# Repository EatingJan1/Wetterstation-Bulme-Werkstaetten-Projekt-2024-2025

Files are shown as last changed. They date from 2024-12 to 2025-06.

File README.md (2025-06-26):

# Completed school project - archived
the project continues here: https://github.com/EatingJan1/BlueRubberDuck-Weatherstation

## Wetterstation-Bulme-Werkstätten-Projekt-2024/2025

#### Outdoor-Wetterstation
Sensoren:
- BME688: xyz
- UV-Strahlung 
- Luftdruck -> easy BME680(END OF LIVE)/BME688 ist bisl besser und gleiches PINOUT und kostet nur weniger 1€ teurer
- Luftpartikel -> gehackter von Ikea(belüftet Lüfter drin)
- Temperatur -> easy BME680(END OF LIVE)/BME688 ist bisl besser und gleiches PINOUT und kostet nur weniger 1€ teurer
- Regenmenge -> Kippwage & Regenitensität über Zeit
- Windrichtung
- Windgeschwindigkeit
- Bodenfeuchtigkeit 
- UV-Strahlung Winkel -> Berechnen durch von Geolocation
- Dezibel Messung (Optional, Eher nicht)
- Höhenlage -> GPS oder Luftdruck aber zählt eher zu Berchnungen
- CO2 gehalt

##### Belüftete Sensoren  -> Mit 5V Lüfter -> ideal ohne moglichkeit ohne Lüfter
- Temperatur
- Luftfeuchtigkeit
- CO2 Gehalt
- Luftdruck
- Luftpartikel -> gehackter von Ikea (Lüfter drin) -> Teurer es zu hacken / aus zu bauen wie einen Neuen zu Kaufen

##### Berechnung:
- Taupunkt
- kWh/m2 (Sonneneinstrahlung) -> Mehrere Sensoren notwendig zu aufwendig
- gefühlte Temperatur -> Wind + Temp +Sonneneinstrahlung Vielleicht Über temperatur direkt an der gehäusewand ob eher hohe Sonneneinstrahlung oder niedrige 
- Sichtweite -> Feinstaub wichtig 
- Photovoltaik für Outdoor -> Zu viele Variablen
- Windmessung über Ultraschalwandler

##### Funk:
Übertragung: Thread

#### Mini Station:

Misst alle Daten in einem Standard Indoor Raum

Gewollte Messung:
- Temperatur
- Luftfeuchtigkeit
- CO2 Gehalt
- Luftdruck
- Helligkeit (Photowiderstand)

##### Funk:
Übertragung: Thread

#### Daten Station (HUB)
Schittstelle zu unserer Datenbank und ins Local Area Network zur überwachung der Daten

- SD Karten speicherung
- Lan anstatt Wlan
- Lan Driver
- Power über POE
- Überträgt alle Messdaten der letzen seit dem Letzten Timestamp der Datenbank einmalig pro Tag auf unseren MySQL Server. (Welche möglichkeit bzw. Daten auf mehrere Server senden)
    - Server Jan:
        - Im Falle eines Ausfall -> Selbständige Lösung, jedoch Auafall wahrscheinlichkeit höher
        - Gefahr das Daten beschädigt werden / Gelöscht
        - Komplette Administration aller Daten und des Ganzen Systems
        - Individuelle Leistung und weiterleitung (DNS)

    - Schul SQL Datenbank:
        - Keine Informationen über Systemabschaltungen (Wartungs arbeiten, Sommerferien)
        - Keine Informationen von Dauer der Daten speicherung
        - Auf System Administrator angewießen
        - Keine Leistungs bestimmung
        - Kein Eingriff ins Netzwerk
    
    - Externe SQL Server Anbieter:
        - Teuer -> Lohnt sich bei dieser Art von Projekt
        - Hohe Ausfahl Sicherheit
        - Fast keine Gefahr das Daten beschädigt werden
        - Teils auf Support angewießen.
        - Je besser die Hardware desto Teurer pro Monat wobei der Server der selbe bleibt.
        - Netzwerk Limitierungen (Aufpreise)
        - Kann von Datenlacks betroffen sein.

#### Stromversorgung für ALLE STATIONEN:
- USB C 5V -> 3,3V Step-down Converter

## Liste der Sachen für das Projekt:

### ESP's

- Router-CPU: ESP32-S3 -> Externe Antenne -> schlecht, Bessere Reichweiten Kontrolle
- Router-Thread: ESP32-H2 -> Externe Antenne -> schlecht, Bessere Reichweiten Kontrolle
- Devices: ESP32-C6 -> Externe Antenne -> schlecht, Bessere Reichweiten Kontrolle

Externe Antenne:
    https://www.mouser.at/ProductDetail/Johanson-Technology/2450AT14A0100Tqs=YCa%2FAAYMW01CU618jkZ%252BCw%3D%3D&mgh=1&vip=1&utm_id=20600977424&gad_source=1&gbraid=0AAAAA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

### Sensor List:

<table>
 <tr height=20 style='height:15.0pt'>
  <td height=20 class=xl66 width=124 style='height:15.0pt;width:93pt'>Name</td>
  <td class=xl66 width=143 style='width:107pt'>Zweck</td>
  <td class=xl66 width=143 style='width:107pt'>Einheit</td>
  <td class=xl67 width=977 style='width:733pt'>&nbsp;</td>

 <tr height=20 style='height:15.0pt'>
  <td height=20 class=xl65 style='height:15.0pt'>PT 100/1000</td>
  <td class=xl65>Temperaturmessung</td>
  <td class=xl65>°C</td>
  <td></td>
 </tr>
 <tr height=20 style='height:15.0pt'>
  <td height=20 class=xl65 style='height:15.0pt'>Platine</td>
  <td class=xl65>Luftfeuchtigkeit</td>
  <td class=xl65>%</td>
  <td></td>
 </tr>
 <tr height=20 style='height:15.0pt'>
  <td height=20 class=xl65 style='height:15.0pt'>CCS811B-JOPR5K</td>
  <td class=xl65>Luftqualität</td>
  <td class=xl65>ppm</td>
  <td>https://www.digikey.at/de/products/detail/sciosense/CCS811B-JOPR5K/7428298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</td>
 </tr>
 <tr height=20 style='height:15.0pt'>
  <td height=20 class=xl65 style='height:15.0pt'>BMP280</td>
  <td class=xl65>Luftdruck</td>
  <td class=xl65>bar</td>
  <td>https://at.rs-online.com/web/p/drucksensor-ics/8496187</td>
 </tr>
 <tr height=20 style='height:15.0pt'>
  <td height=20 class=xl65 style='height:15.0pt'></td>
  <td class=xl65></td>
  <td class=xl65></td>
  <td></td>
 </tr>
 <tr height=0 style='display:none'>
  <td width=124 style='width:93pt'></td>
  <td width=143 style='width:107pt'></td>
  <td width=143 style='width:107pt'></td>
  <td width=977 style='width:733pt'></td>
 </tr>
</table>

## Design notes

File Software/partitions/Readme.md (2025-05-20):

# Custom Partition Tables on ESP32 (PlatformIO)

Why Use Custom Partitions?

The default partition table on the ESP32 is suitable for simple projects, but many applications need a different memory layout. Here are some reasons why you might want to use a custom partition table:

* Larger SPIFFS or LittleFS Storage: Need more space for files? Increase the size of your file system partition.
* Multiple App Partitions: For over-the-air (OTA) updates or fallback firmware.
* NVS Tweaks: Allocate more room for non-volatile storage (NVS).
* Custom Data Sections: Store configuration data, logs, or calibration values in dedicated partitions.
* PSRAM Optimization: Match partitioning to specific PSRAM setups.
Custom partitioning helps you get the most out of your flash memory depending on your application’s needs.

Update platformio.ini to Use the Custom Partition
Add or modify the board_build.partitions option:

## Update `platformio.ini` to Use the Custom Partition Table

To tell PlatformIO to use your custom partition layout, open your `platformio.ini` file and add or modify the following line:

```ini
board_build.partitions = partitions/partitions.csv
[env:esp32dev]
platform = espressif32
board = esp32dev
framework = arduino

;Use a custom partition layout
board_build.partitions = partitions/partitions.csv
```

📁 Make sure your partitions.csv file is located in the partitions/ subfolder of your project directory.
PlatformIO will automatically include this partition scheme when compiling and flashing your project.

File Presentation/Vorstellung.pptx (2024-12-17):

## Wetterstation

## Must2Have

Indoor:
- Temperatur
- Luftfeuchtigkeit
- Luftdruck
- CO2

Outdoor:
- Temperatur
- Luftfeuchtigkeit
- Luftdruck
- Regenmenge
- Windrichtung
- Windgeschwindigkeit

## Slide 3

Blockschaltbild
Minimaler Ausbau

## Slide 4

Nice2Have

Indoor:
LED‘s→ Visualisierung von Optimal werten
Luftpartikel

Outdoor:
Luftpartikelsensor
Sonnenlichtabhängige Sensoren
Windmessung über Ultraschall
Gefühlte Temperatur

## Nice2Have Berechnungen

Outdoor:
Sichtweite
Einstrahlungsenergie pro m²
kWh/m² (Sonneneinstrahlung)
Taupunkt

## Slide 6

Nice2Have

Für alle Geräte:
OTA → ermöglicht Updates von Anwendungen, Diensten und Konfigurationen über ein Funknetz – ohne physischen Kontakt, also over the air
HUB:
Power over Ethernet (POE) → Ermöglicht es Daten und elektrische Energie über einen RJ-45 Kabel zu transportieren
Datenspeicherung über längere Zeit

Second Outdoor Sensor:
Bodenfeuchtigkeit

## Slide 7

Nice2Have
Funkprotokoll:
Thread

Vorteile gegenüber WLAN:
Geringer Stromverbrauch
Unterstützt Mesh-Netzwerke → Geräte können direkt miteinander kommunizieren und Signale weiterleiten
Ist besser für Smart-Home Geräte ausgelegt
Thread-Netzwerke können Tausende von Geräten effizient verbinden
arbeitet in einem Frequenzbereich der weniger überlastet ist
Beinhaltet integrierte Sicherheitsfunktionen
Es gibt keinen zentralen Router

## Blockschaltbild Maximaler Ausbau

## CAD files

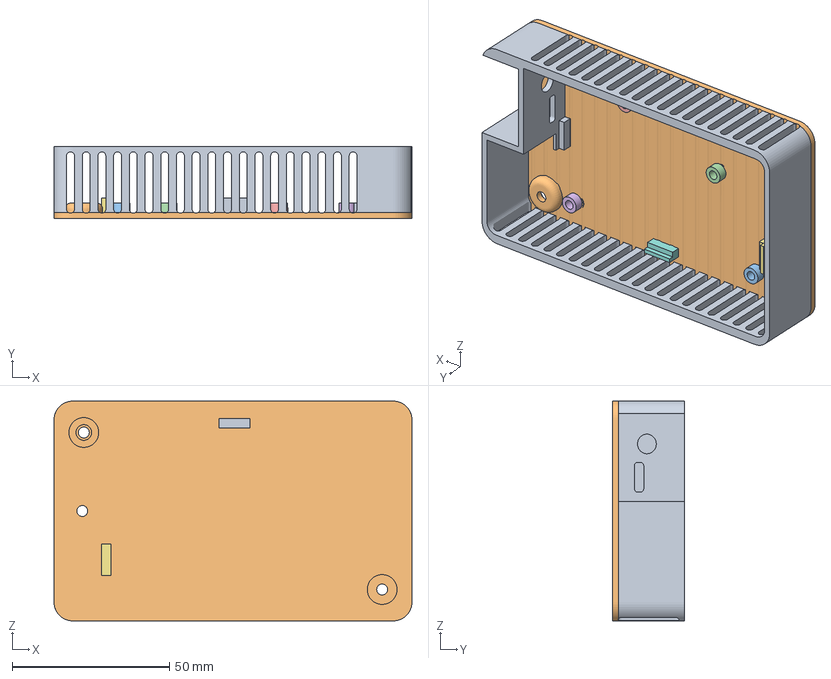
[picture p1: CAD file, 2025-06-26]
3D Model/Indoor/Indoor-bottom v34.3mf
114.0 x 23.0 x 70.0 mm
Außenwand
Grundplatte
HalterungP1
HalterungP2
HalterungP3
HalterungP4
PStütze1 (1)
PStütze1
PStütze3

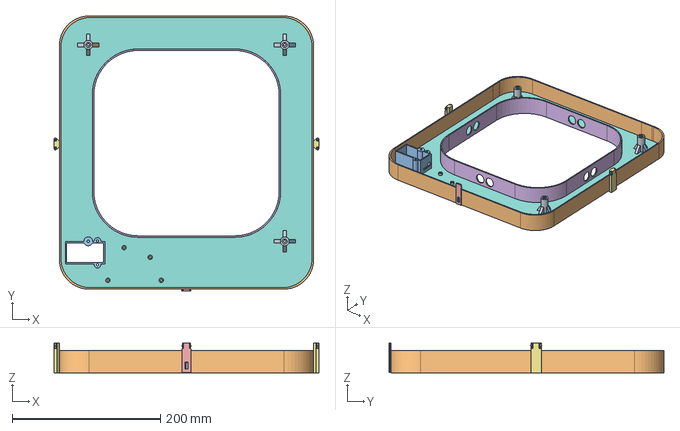
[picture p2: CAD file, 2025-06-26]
3D Model/Outdoor/Outdoor-bottom v38.step
357.0 x 371.0 x 40.0 mm

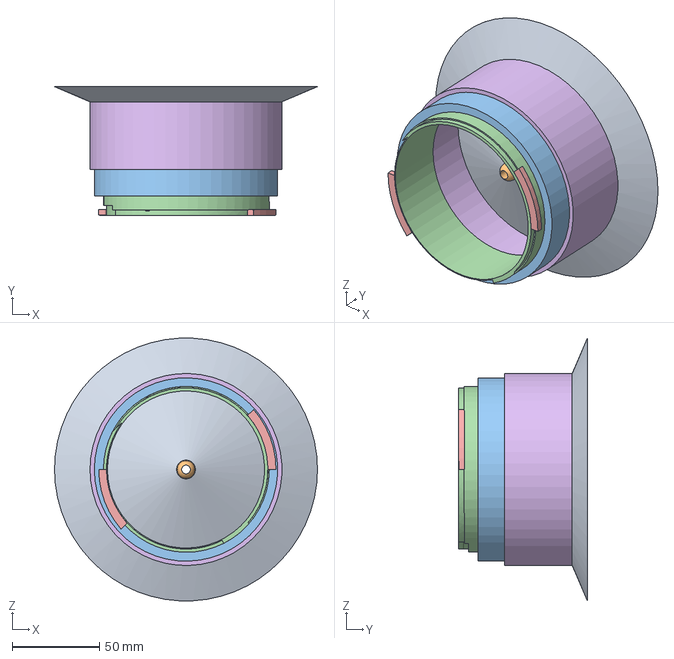
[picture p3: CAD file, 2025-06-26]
3D Model/Outdoor/Hyetometer-top v23.step
150.7 x 73.7 x 150.5 mm

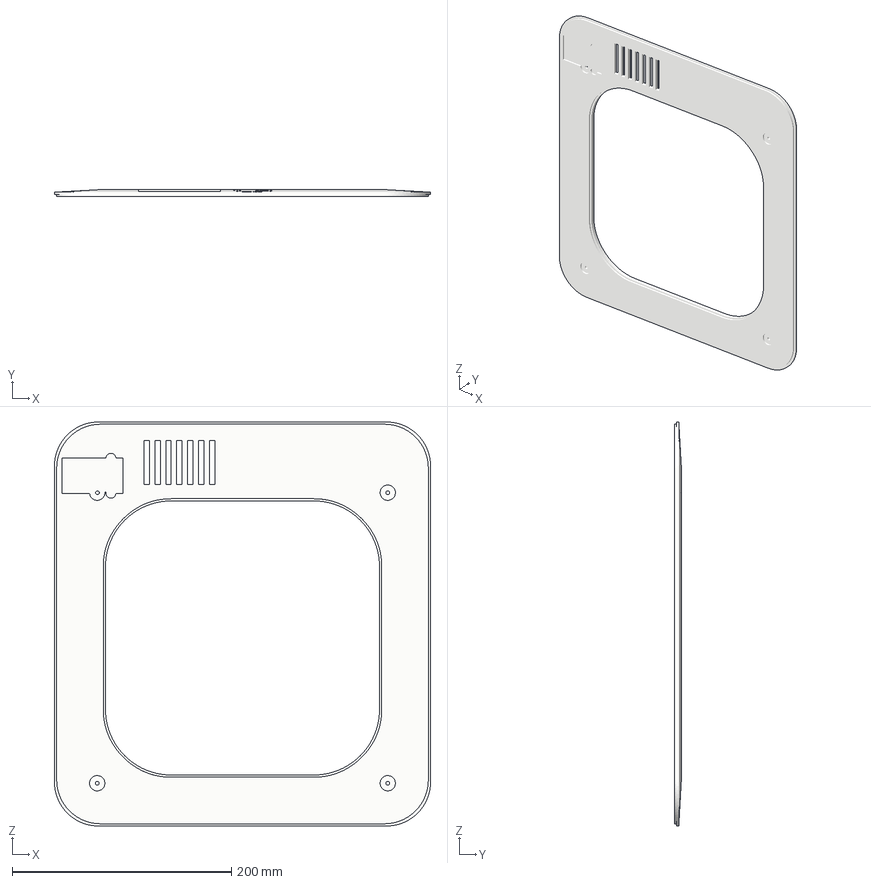
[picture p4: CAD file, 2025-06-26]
3D Model/Outdoor/Outdoor-top v38.3mf
343.0 x 6.50 x 368.5 mm
Körper37
Körper39
Körper40

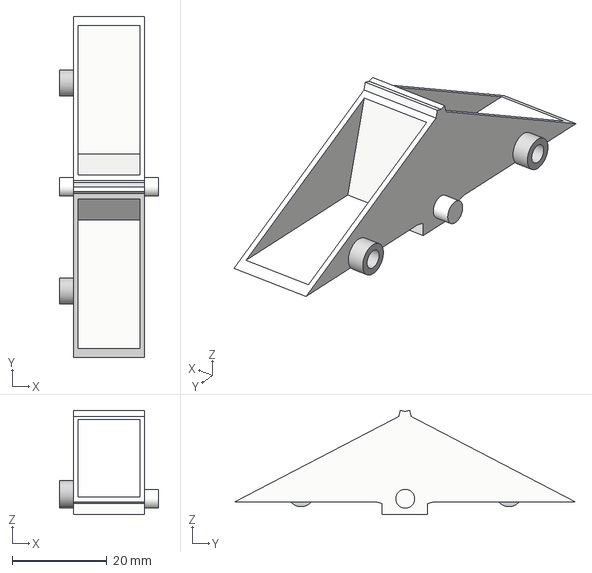
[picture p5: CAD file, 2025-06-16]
3D Model/Outdoor/threshold-Hyetometer v4.step
21.0 x 72.0 x 22.0 mm

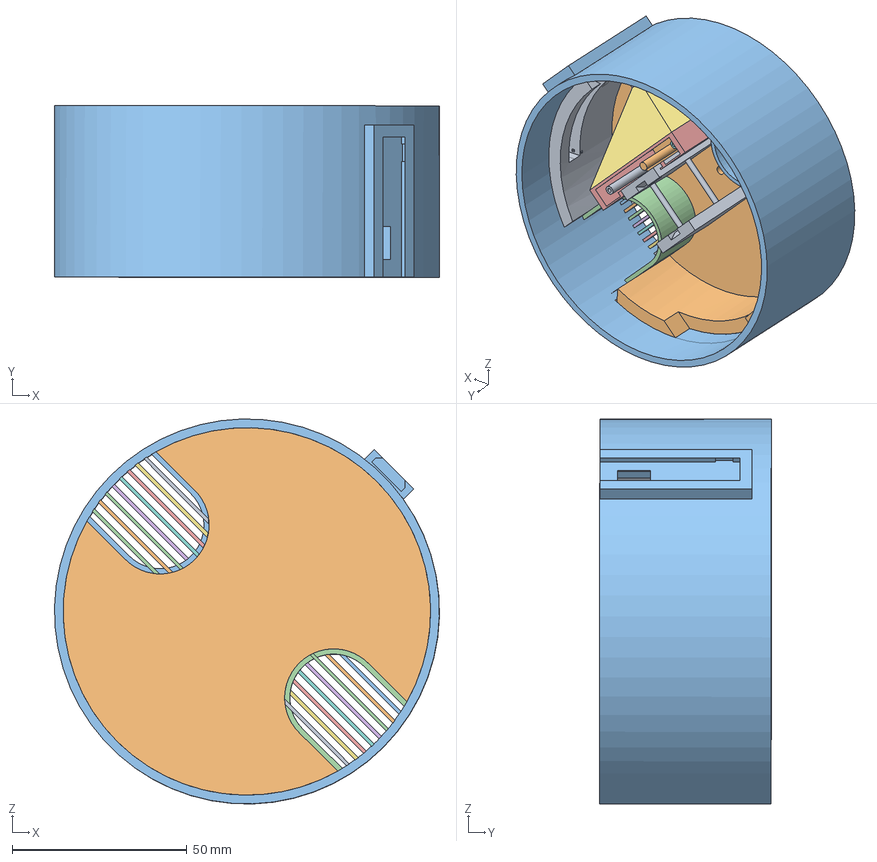
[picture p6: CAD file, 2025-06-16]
3D Model/Outdoor/Trichter-bottom v22.step
110.0 x 49.2 x 110.0 mm

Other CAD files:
3D Model/Outdoor/Hyetometer-bottom v22.3mf
3D Model/Indoor/Indoor-bottom v34.stl
3D Model/Outdoor/Hyetometer-bottom v22.stl
3D Model/Outdoor/Hyetometer-top v23.3mf
3D Model/Outdoor/Hyetometer-top v23.stl
3D Model/Outdoor/Outdoor-bottom v38.3mf
3D Model/Outdoor/Outdoor-bottom v38.stl
3D Model/Outdoor/threshold-Hyetometer v4.3mf
3D Model/Outdoor/threshold-Hyetometer v4.stl

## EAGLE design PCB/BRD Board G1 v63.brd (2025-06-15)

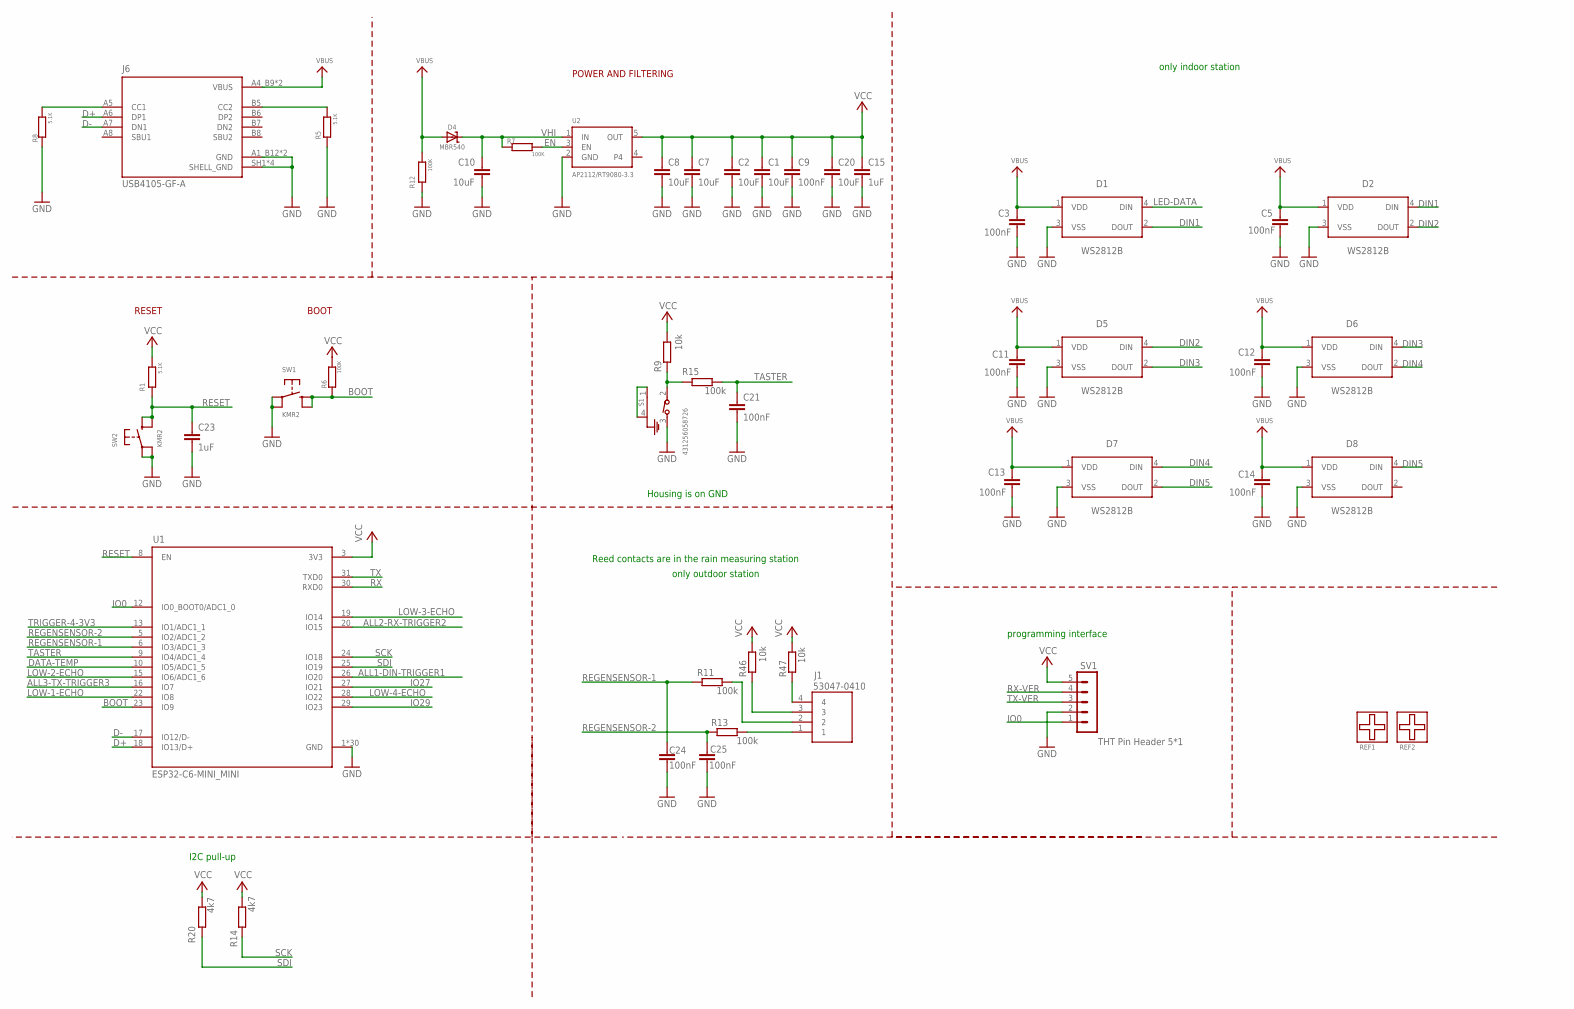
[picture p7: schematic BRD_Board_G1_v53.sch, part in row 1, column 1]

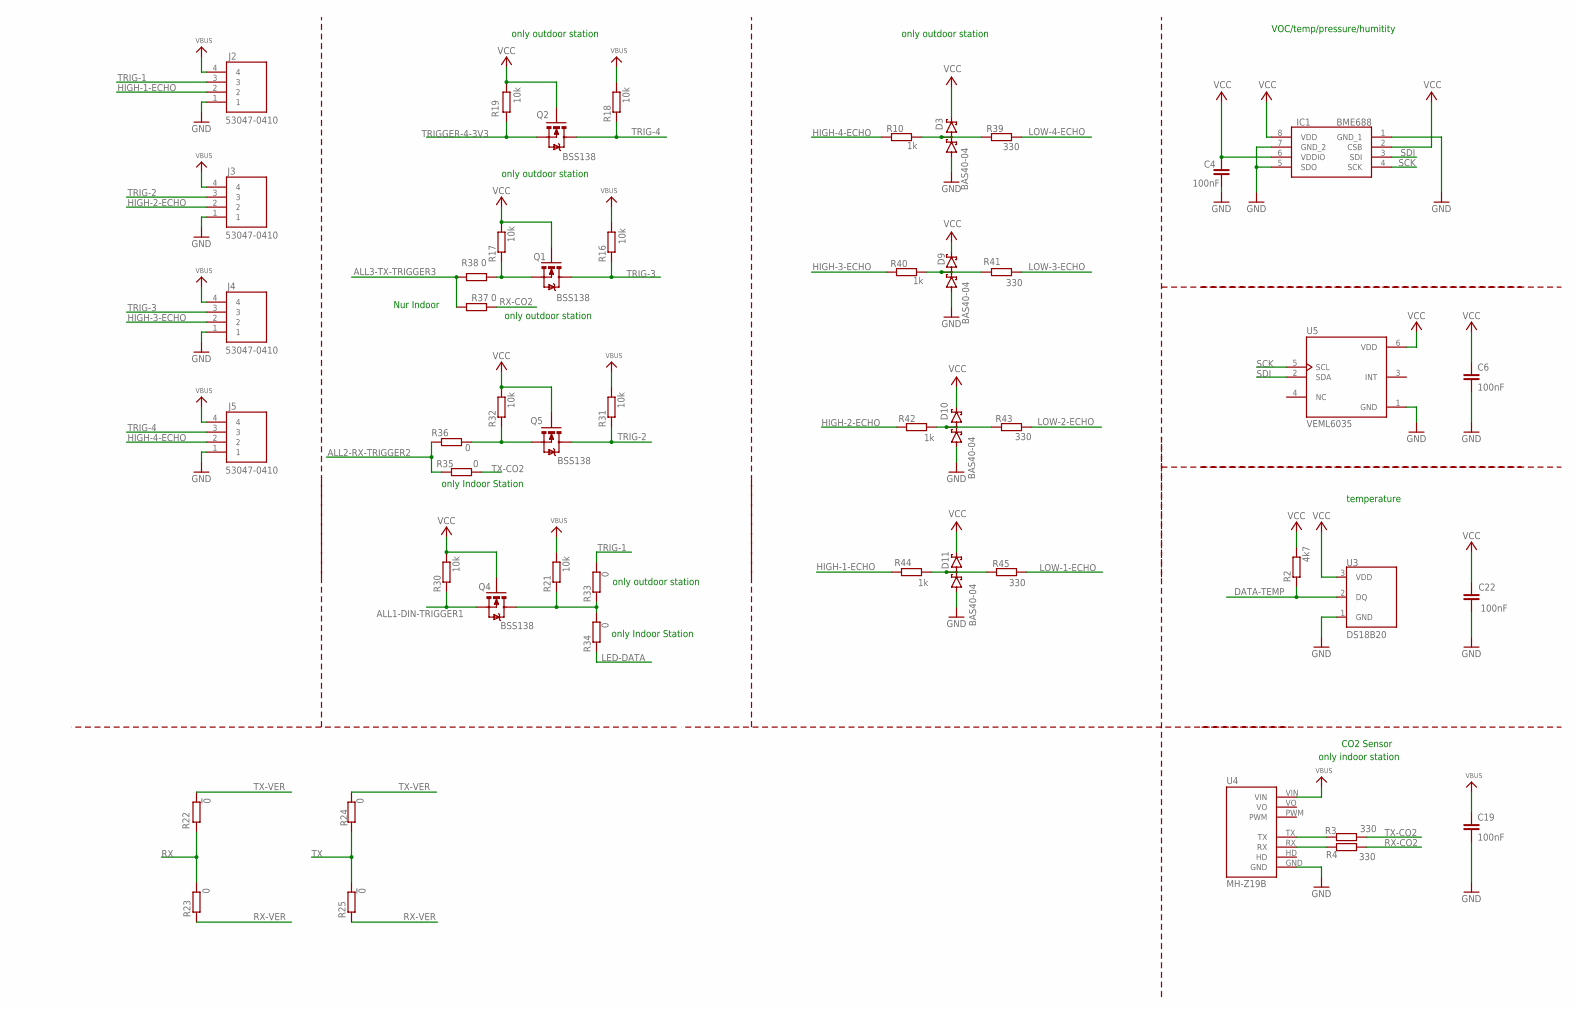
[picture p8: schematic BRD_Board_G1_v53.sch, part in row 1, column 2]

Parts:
C1, C2, C7, C8, C10, C20: 10uF; C0805K
C3, C4, C5, C6, C9, C11, C12, C13, C14, C19, C21, C22, C24, C25: 100nF; C0603K
C15: 1uF; C0603K
C23: 1uF; C0805K
D1, D2, D5, D6, D7, D8: WS2812B
D3, D9, D10, D11: BAS40-04; SOT23
D4: MBR540; SOD-123
IC1: BME688
J1, J2, J3, J4, J5: 53047-0410; 530470410
J6: USB4105-GF-A; GCT_USB4105-GF-A
Q1, Q2, Q4, Q5: BSS138; SOT23
R1, R5, R8: 5.1K; R0805
R2, R14, R20: 4k7; R0805
R3, R4, R39, R41, R43, R45: 330; R0805
R6, R7, R12: 100K; R0805
R9, R16, R17, R18, R19, R21, R30, R31, R32, R46, R47: 10k; R0805
R10, R40, R42, R44: 1k; R0805
R11, R13, R15: 100k; R0805
R22, R25: !0; R0805
R23, R24, R33, R34, R35, R36, R37, R38: 0; R0805
REF1, REF2: FIDUCIALFIDU_1_3_MM; FIDU_1_3MM
S1: 431256058726; 4312560587X6
SV1: THT Pin Header 5*1; MAR05-1
SW1, SW2: KMR2; BTN_RKB2_4.6X2.8
U1: ESP32-C6-MINI_MINI; ESP32-PICO-MINI
U2: AP2112/RT9080-3.3; SOT23-5; JLC_ROTATION 0
U3: DS18B20; TO-92-AMMO
U4: MH-Z19B
U5: VEML6035; XDCR_VEML6035

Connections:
ALL1-DIN-TRIGGER1: Q4.2 (S), R30.1, U1.26 (IO20)
ALL2-RX-TRIGGER2: R35.1, R36.1, U1.20 (IO15)
ALL3-TX-TRIGGER3: R37.1, R38.1, U1.16 (IO7)
BOOT: R6.1, SW1.B (S), SW1.B' (S1), U1.23 (IO9)
D+: J6.A6 (DP1), U1.18 (IO13/D+)
D-: J6.A7 (DN1), U1.17 (IO12/D-)
DATA-TEMP: R2.1, U1.10 (IO5/ADC1_5), U3.2 (DQ)
DIN1: D1.2 (DOUT), D2.4 (DIN)
DIN2: D2.2 (DOUT), D5.4 (DIN)
DIN3: D5.2 (DOUT), D6.4 (DIN)
DIN4: D6.2 (DOUT), D7.4 (DIN)
DIN5: D7.2 (DOUT), D8.4 (DIN)
EN: R7.1, U2.3 (EN)
GND: C1.2, C2.2, C3.2, C4.1, C5.2, C6.2, C7.2, C8.2, C9.2, C10.2, C11.2, C12.2, C13.2, C14.2, C15.2, C19.2, C20.2, C21.2, C22.1, C23.2, C24.2, C25.2, D1.3 (VSS), D2.3 (VSS), D3.1 (A1), D5.3 (VSS), D6.3 (VSS), D7.3 (VSS), D8.3 (VSS), D9.1 (A1), D10.1 (A1), D11.1 (A1), IC1.1 (GND_1), IC1.5 (SDO), IC1.7 (GND_2), J2.1, J3.1, J4.1, J5.1, J6.A1_B12 (GND), J6.B1_A12 (GND), J6.SH1 (SHELL_GND), J6.SH2 (SHELL_GND), J6.SH3 (SHELL_GND), J6.SH4 (SHELL_GND), R5.1, R8.1, R12.1, S1.3, SV1.2, SW1.A, SW1.A' (P1), SW2.A, SW2.A' (P1), U1.1 (GND), U1.2 (GND), U1.11 (GND), U1.14 (GND), U1.36 (GND), U1.37 (GND), U1.38 (GND), U1.39 (GND), U1.40 (GND), U1.41 (GND), U1.42 (GND), U1.43 (GND), U1.44 (GND), U1.45 (GND), U1.46 (GND), U1.47 (GND), U1.48 (GND), U1.49 (GND), U1.50 (GND), U1.51 (GND), U1.52 (GND), U1.53 (GND), U1.54 (GND), U1.55 (GND), U1.56 (GND), U1.57 (GND), U1.58 (GND), U1.59 (GND), U1.60 (GND), U1.61 (GND), U2.2 (GND), U3.1 (GND), U4.GND, U5.1 (GND)
HIGH-1-ECHO: J2.2, R44.2
HIGH-2-ECHO: J3.2, R42.2
HIGH-3-ECHO: J4.2, R40.2
HIGH-4-ECHO: J5.2, R10.2
IO0: SV1.1, U1.12 (IO0_BOOT0/ADC1_0)
IO27: U1.27 (IO21)
IO29: U1.29 (IO23)
LED-DATA: D1.4 (DIN), R34.1
LOW-1-ECHO: R45.1, U1.22 (IO8)
LOW-2-ECHO: R43.1, U1.15 (IO6/ADC1_6)
LOW-3-ECHO: R41.1, U1.19 (IO14)
LOW-4-ECHO: R39.1, U1.28 (IO22)
unnamed: R4.2, U4.RX
unnamed: R9.1, R15.2, S1.2
unnamed: R3.2, U4.TX
unnamed: S1.1 (GND1), S1.4 (GND)
unnamed: D3.3 (C1A2), R10.1, R39.2
unnamed: D9.3 (C1A2), R40.1, R41.2
unnamed: Q1.2 (S), R17.1, R38.2
unnamed: J6.A5 (CC1), R8.2
unnamed: J6.B5 (CC2), R5.2
unnamed: D10.3 (C1A2), R42.1, R43.2
unnamed: D11.3 (C1A2), R44.1, R45.2
unnamed: J1.3, R46.1
unnamed: J1.4, R47.1
unnamed: Q5.2 (S), R32.1, R36.2
unnamed: Q4.3 (D), R21.1, R33.1, R34.2
unnamed: J1.2, R11.1
unnamed: J1.1, R13.1
REGENSENSOR-1: C24.1, R11.2, U1.6 (IO3/ADC1_3)
REGENSENSOR-2: C25.1, R13.2, U1.5 (IO2/ADC1_2)
RESET: C23.1, R1.1, SW2.B (S), SW2.B' (S1), U1.8 (EN)
RX: R22.2, R23.1, U1.30 (RXD0)
RX-CO2: R4.1, R37.2
RX-VER: R23.2, R25.2, SV1.4
SCK: IC1.4 (SCK), R14.1, U1.24 (IO18), U5.5 (SCL)
SDI: IC1.3 (SDI), R20.1, U1.25 (IO19), U5.2 (SDA)
TASTER: C21.1, R15.1, U1.9 (IO4/ADC1_4)
TRIG-1: J2.3, R33.2
TRIG-2: J3.3, Q5.3 (D), R31.1
TRIG-3: J4.3, Q1.3 (D), R16.1
TRIG-4: J5.3, Q2.3 (D), R18.1
TRIGGER-4-3V3: Q2.2 (S), R19.1, U1.13 (IO1/ADC1_1)
TX: R24.2, R25.1, U1.31 (TXD0)
TX-CO2: R3.1, R35.2
TX-VER: R22.1, R24.1, SV1.3
VBUS: C3.1, C5.1, C11.1, C12.1, C13.1, C14.1, C19.1, D1.1 (VDD), D2.1 (VDD), D4.A, D5.1 (VDD), D6.1 (VDD), D7.1 (VDD), D8.1 (VDD), J2.4, J3.4, J4.4, J5.4, J6.A4_B9 (VBUS), J6.B4_A9 (VBUS), R12.2, R16.2, R18.2, R21.2, R31.2, U4.VIN
VCC: C1.1, C2.1, C4.2, C6.1, C7.1, C8.1, C9.1, C15.1, C20.1, C22.2, D3.2 (C2), D9.2 (C2), D10.2 (C2), D11.2 (C2), IC1.2 (CSB), IC1.6 (VDDIO), IC1.8 (VDD), Q1.1 (G), Q2.1 (G), Q4.1 (G), Q5.1 (G), R1.2, R2.2, R6.2, R9.2, R14.2, R17.2, R19.2, R20.2, R30.2, R32.2, R46.2, R47.2, SV1.5, U1.3 (3V3), U2.5 (OUT), U3.3 (VDD), U5.6 (VDD)
VHI: C10.1, D4.C, R7.2, U2.1 (IN)

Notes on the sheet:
POWER AND FILTERING
RESET
CO2 Sensor
temperature
VOC/temp/pressure/humitity
Reed contacts are in the rain measuring station
programming interface
Housing is on GND
only indoor station
only outdoor station
Nur Indoor
only Indoor Station
BOOT
I2C pull-up

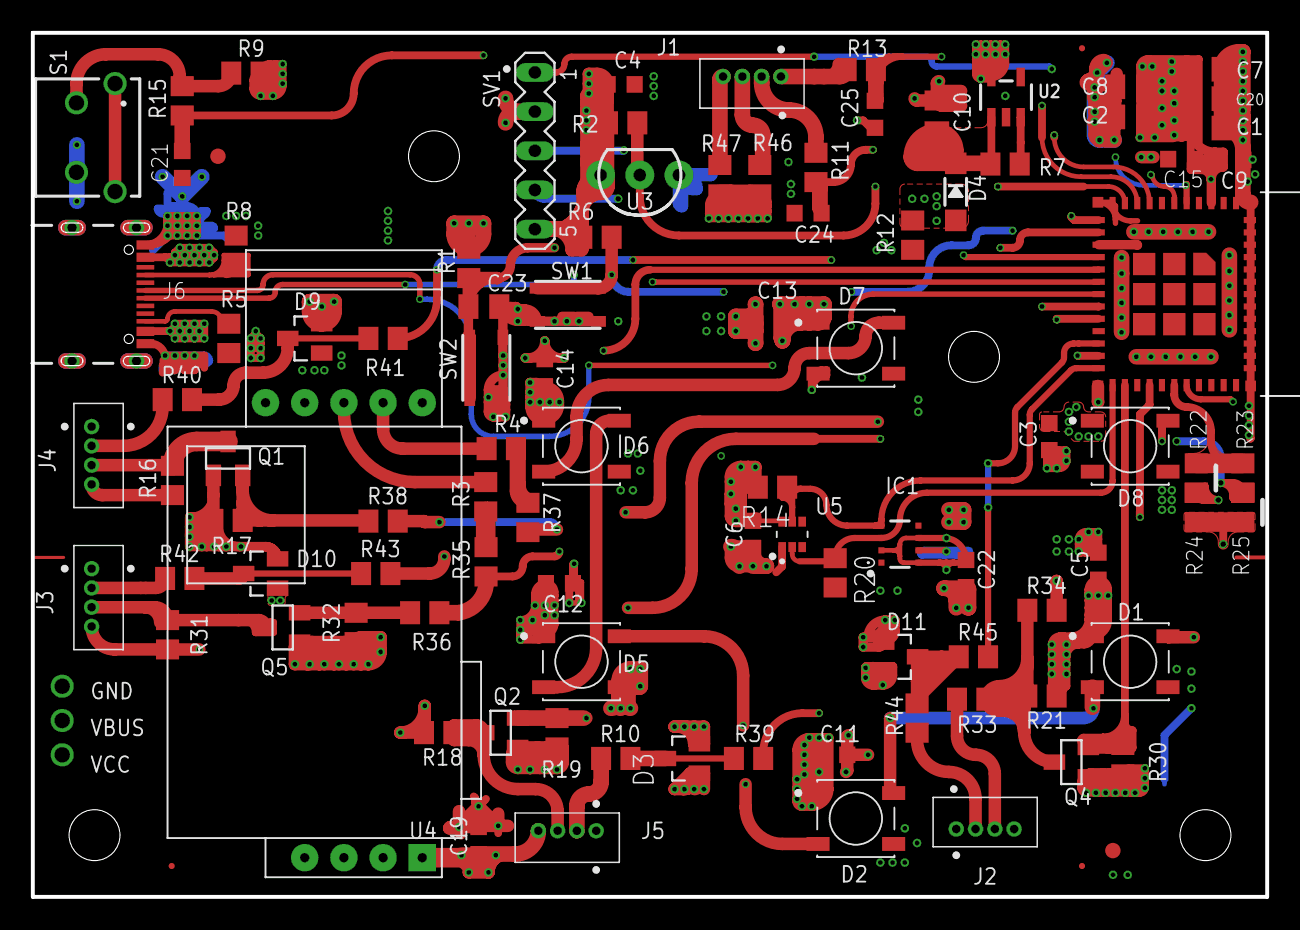
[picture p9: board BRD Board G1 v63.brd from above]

Board: 4 copper layers, 80.0 x 56.0 mm, 98 parts (0 on the bottom side), 61 nets.

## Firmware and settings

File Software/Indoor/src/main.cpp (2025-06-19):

#include <Matter.h>
#include <WiFi.h>
#include "LIB/Matter/matter_endpoints/MatterAirQualitySensor.h"
#include "LIB/Matter/matter_endpoints/MatterLightSensor.h"
#include "LIB/LEDAnimation/LEDAnimation.h"
#include <MHZ19.h>
#include <SoftwareSerial.h>
#include <bme68xLibrary.h>
#include <SparkFun_VEML6030_Ambient_Light_Sensor.h>
#include <Wire.h>

#include "pinout_brd_V1:0.h"

MatterTemperatureSensor Temp;
MatterHumiditySensor Hum;
MatterPressureSensor Pres;
MatterAirQualitySensor CO2;
MatterLightSensor Light;
MatterOnOffPlugin OnOffPlugin;

MHZ19 mhz19;
SoftwareSerial CO2Serial(RX_CO2, TX_CO2);


Bme68x bme;
SparkFun_Ambient_Light light_I2C(AL_ADDR);

Adafruit_NeoPixel strip(NUM_PIXELS, WS2812_Pin, NEO_GRB + NEO_KHZ800);
LEDAnimation Led = LEDAnimation(strip, NUM_PIXELS); 


const char *ssid = "";
const char *password = "";



uint32_t button_time_stamp = 0;                
bool button_state = false;                     
uint32_t time_diff = 0;
const uint32_t decommissioningTimeout = 20000;
const uint32_t co2timer = 5000;

float gain = .125;
int integrationTime = 800;
int powMode = 2; // range [1; 4] 


void setaqilight(uint8_t aqi)
{
    if (1 == aqi)
    {
      Led.setColor(strip.Color(0, 0, 255));
      Led.setAnimation(AnimationType::Static);
    }
    else if (2 == aqi)
    {
      Led.setColor(strip.Color(0, 255, 0));
      Led.setAnimation(AnimationType::Static);
    }
    else if (3 == aqi)
    {
      Led.setColor(strip.Color(213, 78, 0));
      Led.setAnimation(AnimationType::Static);
    }
    else if (4 == aqi)
    {
      Led.setColor(strip.Color(255, 0, 0));
      Led.setAnimation(AnimationType::Static);
    }
    else if (5 == aqi)
    {
      Led.setAnimation(AnimationType::CriticalWarning);
    }
    else
    {
        //Led.setAnimation(AnimationType::None);
    }
}

bool setPluginOnOff(bool state) {
  Serial.printf("User Callback :: New Plugin State = %s\r\n", state ? "ON" : "OFF");
  if (state) {
    setaqilight(CO2.getAirQuality());
  } else {
    Led.setAnimation(AnimationType::None);
  }

  //matterPref.putBool(onOffPrefKey, state);
  return true;
}

void setup() {
  Serial.begin(115200);
  
  Led.setColor(strip.Color(0,0,255));
  Led.setAnimation(AnimationType::StartUp);
  
  delay(1000);

  pinMode(Button_Pin, INPUT);

  WiFi.begin(ssid, password);

  
  // Wait for WiFi connection
  uint32_t counter = 0;
  while (WiFi.status() != WL_CONNECTED) {

    Led.setColor(strip.Color(90, 70, 0));
    Led.setAnimation(AnimationType::Connection);
    // WiFi searching feedback
    Serial.print(".");
    delay(500);
    // adds a new line every 30 seconds
    counter++;
    if (!(counter % 60)) {
      Serial.println();
    }
  }

  Serial.println();



  Led.setAnimation(AnimationType::None);

  Temp.begin();
  Hum.begin();
  Pres.begin();
  Light.begin();
  CO2.begin();
  OnOffPlugin.begin(true);
  OnOffPlugin.onChange(setPluginOnOff);

  Matter.begin();


  if (!Matter.isDeviceCommissioned()) {
    Serial.println("");
    Serial.println("Indoor weather Station is not commissioned yet.");
    Serial.println("Initiate the device discovery in your Matter environment.");
    Serial.println("Commission it to your Matter hub with the Matter Label");
    Serial.printf("Manual pairing code: %s\r\n", Matter.getManualPairingCode().c_str());
    Serial.printf("QR code URL: %s\r\n", Matter.getOnboardingQRCodeUrl().c_str());
    
    Led.setColor(strip.Color(0,0,255));   
    Led.setAnimation(AnimationType::Rotating);

    uint32_t timeCount = 0;


    while (!Matter.isDeviceCommissioned()) {
      delay(100);
      if ((timeCount++ % 100) == 0) {
        Serial.println("Indoor weather Station not commissioned yet. Waiting for commissioning.");
      }
    }
    
    Serial.println("Indoor weather Station is commissioned and connected to Wi-Fi. Ready for use.");
    Led.setAnimation(AnimationType::None);
  }
  if(Matter.isDeviceCommissioned())
  {
    OnOffPlugin.updateAccessory();  // configure the Plugin based on initial state
  }

  CO2Serial.begin(9600);
  mhz19.begin(CO2Serial);

  mhz19.autoCalibration(true);

  Wire.begin(SDI, SCK, 100000);

  bme.begin(BME_ADDR, Wire);
  
  if(bme.checkStatus())
	{
    if (bme.checkStatus() == BME68X_ERROR)
		{
      Serial.println("Sensor error:" + bme.statusString());
		}
		else if (bme.checkStatus() == BME68X_WARNING)
		{
      Serial.println("Sensor Warning:" + bme.statusString());
		}
	}
  
  bme.setTPH();
  bme.setHeaterProf(300, 100);
  

  if(light_I2C.begin())
  Serial.println("Ready to sense some light!"); 
  else
    Serial.println("Could not communicate with the sensor!");
  
  light_I2C.setGain(gain);
  light_I2C.setIntegTime(integrationTime);

  light_I2C.setPowSavMode(powMode);
  light_I2C.enablePowSave();

}

void loop() {
  static uint32_t timeCounter = 0;

  if (!(timeCounter++ % 10)) { 
    //TODO: For long term use Change Time %300(5min) or %600(10min) or % 900(15min)
  	bme68xData data;

    Serial.printf("Current Temperature is %.02f °C\r\n", Temp.getTemperature());
    Serial.printf("Current Humidity is %.02f %\r\n", Hum.getHumidity());
    Serial.printf("Current Pressure is %.02f hPa\r\n", Pres.getPressure());
    Serial.printf("Current Light is %d Lux\r\n", Light.getlight());
    Serial.printf("Sensor Light is %d Lux\r\n", light_I2C.readLight());
    Serial.printf("Current C02 is %.02f ppm\r\n", CO2.getCO2());
    Serial.printf("Current C02 is %d AQI\r\n", CO2.getAirQuality());

	bme.setOpMode(BME68X_FORCED_MODE);
  Serial.print("LIGHT: ");
  Serial.println(light_I2C.readLight());
	delay(500);
  if (bme.fetchData())
	{
		bme.getData(data);
	  Temp.setTemperature(data.temperature);
    Hum.setHumidity(data.humidity);
    Pres.setPressure(data.pressure);  
  }
    Light.setlight(light_I2C.readLight());
    CO2.setCO2(mhz19.getCO2());

    setaqilight(CO2.getAirQuality());
  }

  if (digitalRead(Button_Pin) == LOW and !button_state) {
    button_time_stamp = millis();
    button_state = true;
  }

  if (digitalRead(Button_Pin) == HIGH and button_state) {
    time_diff = millis() - button_time_stamp;
    OnOffPlugin.toggle();
    button_state = false;
  }

  


  if (time_diff > co2timer and decommissioningTimeout > time_diff)
  {
    Serial.println("Co2 calibrate Mode");
    Led.setColor(strip.Color(255,0,0));
    Led.setAnimation(AnimationType::Connection);
    mhz19.calibrate();
    button_time_stamp = millis();
    time_diff = 0;
    delay(1000);
    Led.setAnimation(AnimationType::None);
  }
  
  if (time_diff > decommissioningTimeout)
  {
    Serial.println("Decommissioning Indoor weather Station. It shall be commissioned again."); 
    Matter.decommission();
    button_time_stamp = millis();
    time_diff = 0;
  }

  delay(500);
}

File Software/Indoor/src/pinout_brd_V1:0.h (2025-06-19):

#ifndef PINOUT_H
#define PINOUT_H


#define SDI 19
#define SCK 18

#define AL_ADDR 0x29
#define BME_ADDR 0x76


#define TX_CO2 7
#define RX_CO2 15


#define WS2812_Pin 20

#define Button_Pin 4

#define Temp_Pin 5

#define Reed1_Pin 3
#define Reed2_Pin 2



#define Trigger_1 20
#define Trigger_2 15
#define Trigger_3 7
#define Trigger_4 1

#define Echo_1 8
#define Echo_2 6
#define Echo_3 14
#define Echo_4 22

#define NUM_PIXELS 6


#endif

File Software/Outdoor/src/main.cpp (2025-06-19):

#include <Matter.h>
#include <WiFi.h>
#include "LIB/Matter/matter_endpoints/MatterFlowSensor.h"
#include "LIB/Matter/matter_endpoints/MatterRainSensorSensor.h"
#include "LIB/Matter/matter_endpoints/MatterLightSensor.h"
#include <SparkFun_VEML6030_Ambient_Light_Sensor.h>
#include <bme68xLibrary.h>
#include <Wire.h>
#include "LIB/Hyetometer/mwippe.h"
#include "LIB/Anemometer/MCAnemometer.h"
#include "LIB/average_per_time/average_per_time.h"


#include "pinout_brd_V1:0.h"


MatterTemperatureSensor Temp;
MatterHumiditySensor Hum;
MatterPressureSensor Pres;
MatterLightSensor Light;
MatterRainSensor Rain;
MatterFlowSensor RainFlow;

Bme68x bme;
SparkFun_Ambient_Light light_I2C(AL_ADDR);

mwippe rain_reed = mwippe(Reed2_Pin, rainunit);
Anemometer anemometer = Anemometer(Trigger_1, Echo_1, Trigger_2, Echo_2, Trigger_3, Echo_3, Trigger_4, Echo_4, distance_wind);

AveragePerTime perHour;

const char *ssid = "";
const char *password = "";


uint32_t button_time_stamp = 0;                
bool button_state = false;                     
uint32_t time_diff = 0;
const uint32_t decommissioningTimeout = 20000;
const uint32_t windtimer = 5000;

float gain = .125;
int integrationTime = 800;
int powMode = 2; // range [1; 4] 

void setup() {
  Serial.begin(115200);
  
  pinMode(Button_Pin, INPUT);

  
  WiFi.begin(ssid, password);
  while (WiFi.status() != WL_CONNECTED) {
    
    delay(500);
    Serial.print(".");
  }
  Serial.println();
  

  Temp.begin();
  Hum.begin();
  Pres.begin();
  Light.begin();
  RainFlow.begin();
  Rain.begin();

  Matter.begin();


  if (!Matter.isDeviceCommissioned()) {
    Serial.println("");
    Serial.println("Outdoor weather Station is not commissioned yet.");
    Serial.println("Initiate the device discovery in your Matter environment.");
    Serial.println("Commission it to your Matter hub with the Matter Label");
    Serial.printf("Manual pairing code: %s\r\n", Matter.getManualPairingCode().c_str());
    Serial.printf("QR code URL: %s\r\n", Matter.getOnboardingQRCodeUrl().c_str());

    
    uint32_t timeCount = 0;
    while (!Matter.isDeviceCommissioned()) {
      delay(100);
      if ((timeCount++ % 100) == 0) {
        Serial.println("Outdoor weather Station not commissioned yet. Waiting for commissioning.");
      }
    }
    Serial.println("Outdoor weather Station is commissioned and connected to Wi-Fi. Ready for use.");
  }



  Wire.begin(SDI, SCK, 100000);

  bme.begin(BME_ADDR, Wire);
  
  if(bme.checkStatus())
	{
    if (bme.checkStatus() == BME68X_ERROR)
		{
      Serial.println("Sensor error:" + bme.statusString());
		}
		else if (bme.checkStatus() == BME68X_WARNING)
		{
      Serial.println("Sensor Warning:" + bme.statusString());
		}
	}
  
  bme.setTPH();
  bme.setHeaterProf(300, 100);

  if(light_I2C.begin())
    Serial.println("Ready to sense some light!"); 
  else
    Serial.println("Could not communicate with the sensor!");
  
  light_I2C.setGain(gain);
  light_I2C.setIntegTime(integrationTime);

  light_I2C.setPowSavMode(powMode);
  light_I2C.enablePowSave();

  rain_reed.readpinstate();
}

void loop() {
  static uint32_t timeCounter = 0;

    if(rain_reed.runcheckerwipp())
    {
      perHour.add(1);
    }
    

  if (!(timeCounter++ % 20)) { //TODO: For long term use Change Time %300(5min) or %600(10min) or % 900(15min)
    bme68xData data;
    
    anemometer.readstate();
    Serial.printf("Current Temperature is %.02f °C\r\n", Temp.getTemperature());
    Serial.printf("Current Humidity is %.02f %\r\n", Hum.getHumidity());
    Serial.printf("Current Pressure is %.02f hPa\r\n", Pres.getPressure());
    Serial.printf("Current Light is %.02f Lux\r\n", Light.getlight());
    Serial.printf("Current Rain is %.02f m^3/h\r\n", RainFlow.getFlow());
    Serial.printf("Rain: %.02d \r\n", Rain.getRain());
    log_i("Current Windspeed is %.02f km/h\r\n",  anemometer.getspeed());
    log_i("Current Windgusts is %.02f km/h\r\n",  anemometer.getgustswind());
    log_i("Current Windangle is %.02f km/h\r\n",  anemometer.getangle());


    bme.setOpMode(BME68X_FORCED_MODE);
	  delay(500);
  if (bme.fetchData())
	{
		bme.getData(data);
	  Temp.setTemperature(data.temperature);
    Hum.setHumidity(data.humidity);
    Pres.setPressure(data.pressure);  
  }
    Light.setlight(light_I2C.readLight());
    Rain.setRain(0);


  float m3 = perHour.getSum(3600000UL)/1000;
  if(m3>0)//TODO: In next Version, check rain from last 15 minuts
  {
    Rain.setRain(1);
  }
  else
  {
    Rain.setRain(0);
  }
  RainFlow.setFlow(m3);

  anemometer.readstate();
  log_i("Angle: %f", anemometer.getangle());
  log_i("Speed: %f", anemometer.getspeed());
  log_i("Guest: %f", anemometer.getgustswind());

  }

  if(digitalRead(Button_Pin) == LOW and !button_state) {
    button_time_stamp = millis();
    button_state = true;
  }

  if(digitalRead(Button_Pin) == HIGH and button_state) {
    time_diff = millis() - button_time_stamp;
    button_state = false;
  }


  if(time_diff > windtimer and decommissioningTimeout > time_diff)
  {
    Serial.println("Anemometer calibrate Mode");
    button_time_stamp = millis();
    time_diff = 0;
  }
  
  if(time_diff > decommissioningTimeout)
  {
    Serial.println("Decommissioning Outdoor weather Station. It shall be commissioned again.");
    Matter.decommission();
    button_time_stamp = millis();
    time_diff = 0;
  }

  delay(500);
}

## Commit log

2024-12-09 Update README.md
    Readme add Sensorlist
2024-12-09 Add Esp32-S3 -> README.md
2024-12-12 Update README.md
    Add Thread
2024-12-17 Add "Blockschaltbild" to powerpoint
2024-12-17 Update Powerpoint
2025-01-06 Update README.md
    Add Thread Netzwerk
2025-01-08 Update README.md
    Add link to Thread Netzwerk
2025-01-20 Move BME688.sch in Schaltplan und Layouts
    [BME688.sch]
2025-01-25 Footprint vom ESP32-H2-MINI-1U
    Pins sollten richtig sein muss nur noch wer doppelt überprüfen
    [Esp32-H2-wroom-u1-Nx.sch]
2025-01-26 jetzt passen die Footprints vom esp32
    vorher VIAs die aus nem unbekannten Grund zu Groß geworden sind und ich nicht verkleinern konnte.
    [ESP32-H2-MINI-1U-passend.sch]
2025-01-26 Delete Schaltplan und Layouts/Esp32-H2-wroom-u1-Nx.sch
    Da falsch
    [Esp32-H2-wroom-u1-Nx.sch]
2025-01-26 Delete Schaltplan und Layouts/ESP32-H2-MINI-1-H2-Pinbelegung-richtig.lbr
    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
2025-01-26 Software Ordner import
    [partitions.csv]
2025-01-27 temp Test erstellt
    [partitions.csv]
2025-01-29 SCHlatplan des 3V3 Step down converter
    [SCHALTPLAN-3V3-Step-down-Converter.sch]
2025-03-11 Add Outdoorwetter
    [Unterseite-Outdoorwetter.f3d]
2025-03-11 Add Stuetze
    [Stütze.f3d]
2025-03-11 Add Wippe
    [Wippe v7.f3d]
2025-03-11 Stütze v2
    [Stütze.f3d, Sütze v2.f3d]
2025-03-25 Schaltplan fertig wahrscheinlich
    [Adafruit Feather ESP32-C6-AUSSEN.sch]
2025-05-13 Add 2 partitions for ESP32; use Matter on 4M Flash
    [1.5MAppD.csv]
2025-05-20 Move folder
    [1.5MAppD.csv, 1.7MAppD.csv, partitions.csv]
2025-06-15 Change PCB
    [Adafruit Feather ESP32-C6-AUSSEN.sch, BME688.sch, BRD Board G1 v63.brd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]
2025-06-15 Update 3d
    [Indoor-bottom v24.3mf, Indoor-bottom v24.stl, Sütze v2.f3d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]
2025-06-16 Change Outdoor
    [Outdoor v36.3mf, Outdoor-bottom v36.3mf, Outdoor-bottom v36.step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]
2025-06-16 CHange Modle
    [Hyetometer-bottom v22.3mf, Hyetometer-bottom v22.stl, Hyetometer-top v22.3mf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]
2025-06-19 Add Submodule MCAnemometer-Ultrasonic
2025-06-19 rm LEDanimation lib
2025-06-19 Changes for new led lib
2025-06-26 Update 3D Versions
    [Hyetometer-top v22.3mf, Hyetometer-top v22.step, Hyetometer-top v22.stl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]

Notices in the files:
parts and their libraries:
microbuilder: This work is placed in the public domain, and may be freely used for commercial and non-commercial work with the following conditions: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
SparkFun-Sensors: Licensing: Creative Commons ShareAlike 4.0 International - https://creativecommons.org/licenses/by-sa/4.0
